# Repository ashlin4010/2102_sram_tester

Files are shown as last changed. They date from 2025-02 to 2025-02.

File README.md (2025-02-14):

# 2102 SRAM Tester #

A basic tester to quickly check 2102 RAM chips. This tester only performs rudimentary tests and is very lax with its timing so it may not fully detect marginal RAM chips.

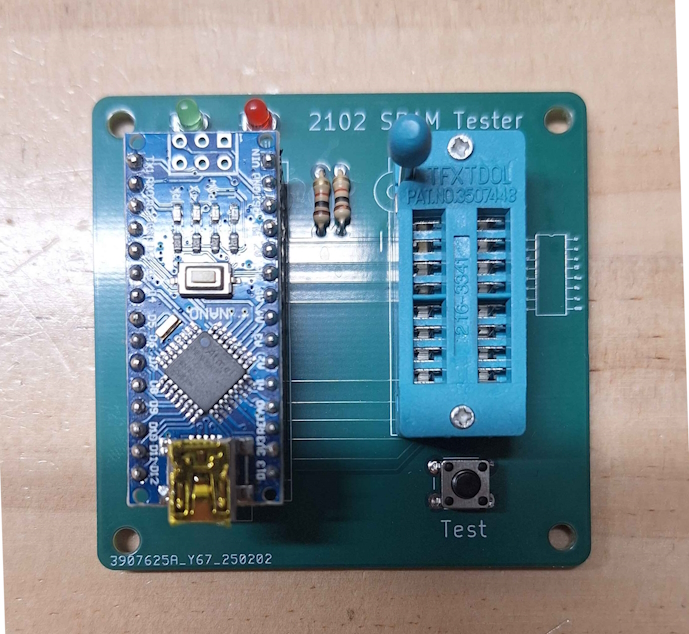
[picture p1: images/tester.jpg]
RAM tester PCB

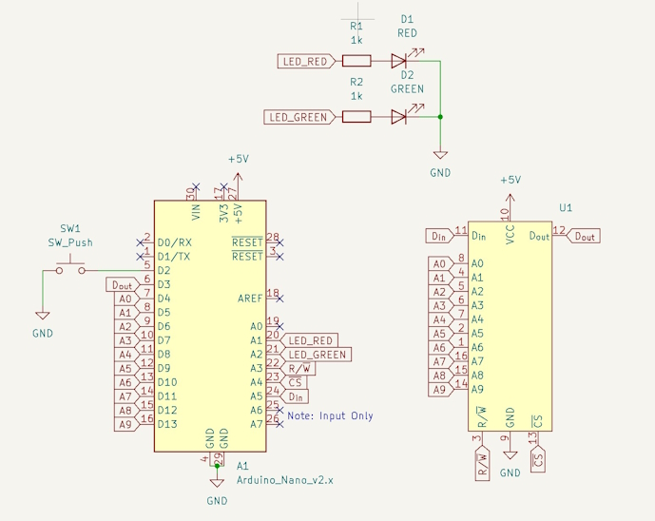
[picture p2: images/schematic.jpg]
RAM schematics


## Firmware ##
The firmware is a quick and dirty Arduino program and makes use of `digitalWrite` and is subsequently very slow. Things could be sped up significantly by writing the firmware in AVR and using timers and cycle counting. The circuit would also benefit from an external latch for the address lines.

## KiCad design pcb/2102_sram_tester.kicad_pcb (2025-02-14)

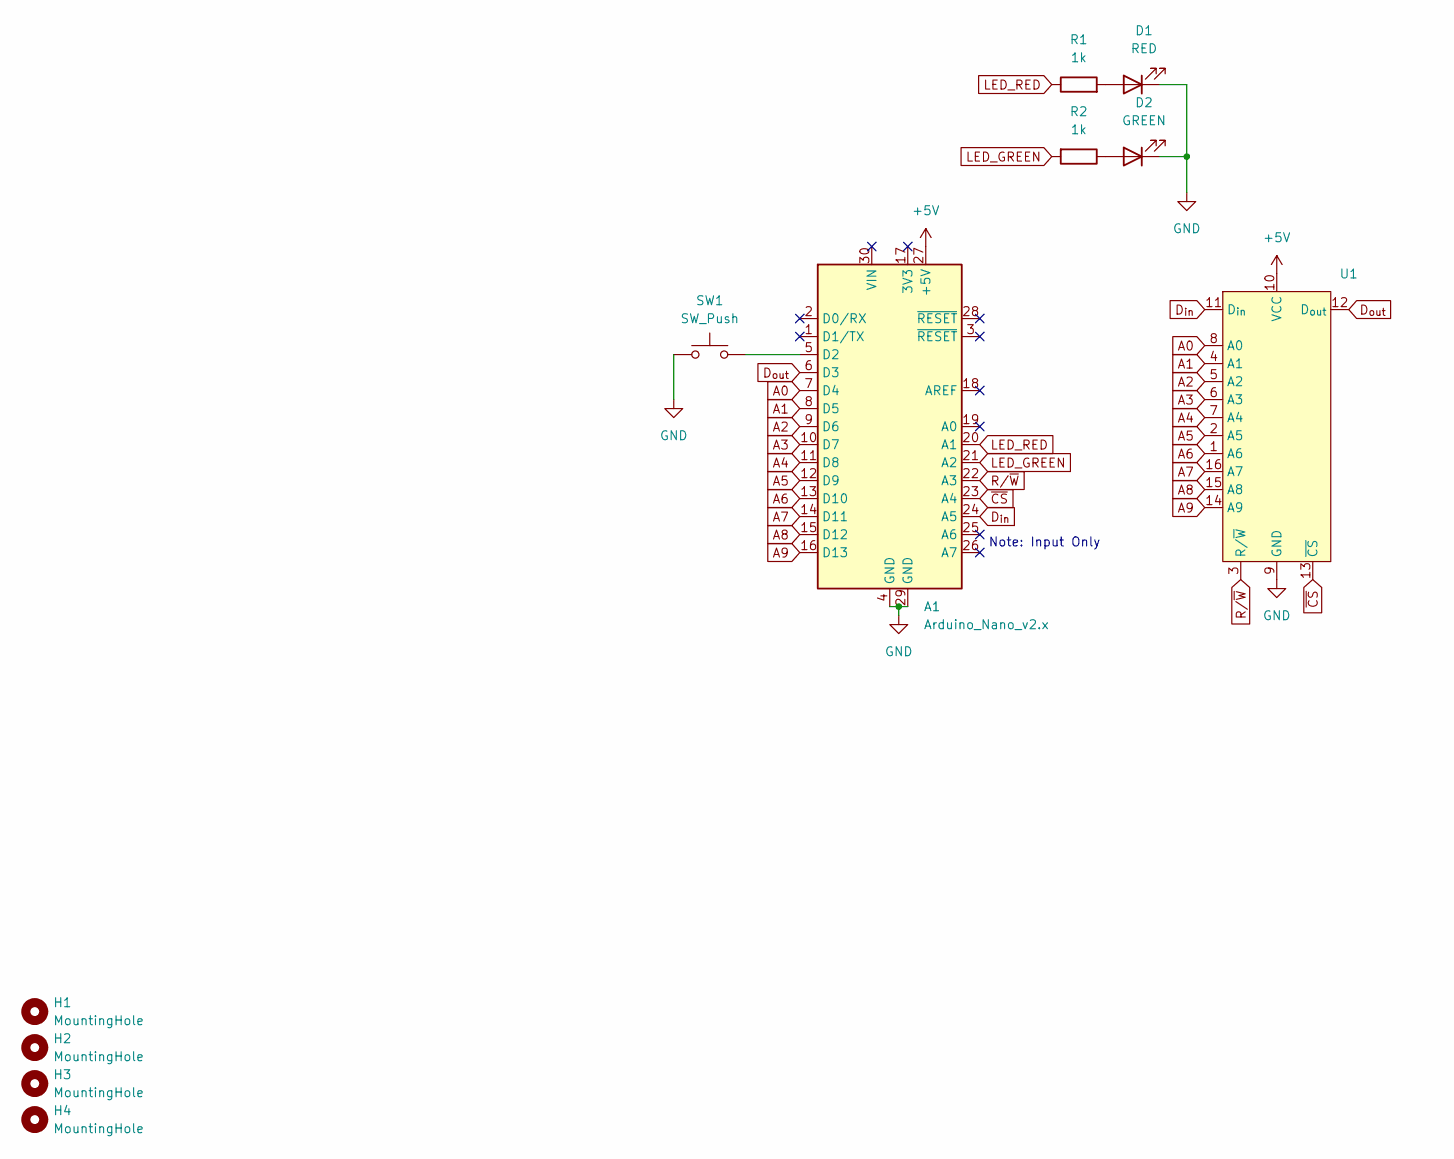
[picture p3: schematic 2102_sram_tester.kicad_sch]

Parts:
A1: Arduino_Nano_v2.x; Arduino_Nano
D1: RED; LED_D3.0mm
D2: GREEN; LED_D3.0mm
H1, H2, H3, H4: MountingHole; MountingHole_3.2mm_M3
R1, R2: 1k; R_Axial_DIN0204_L3.6mm_D1.6mm_P7.62mm_Horizontal
SW1: SW_Push; SW_PUSH_6mm
U1: DIP_Socket-16_W4.3_W5.08_W7.62_W10.16_W10.9_3M_216-3340-00-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

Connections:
+5V: A1.27 (+5V), U1.10 (VCC)
A0: A1.7 (D4), U1.8 (A0)
A1: A1.8 (D5), U1.4 (A1)
A2: A1.9 (D6), U1.5 (A2)
A3: A1.10 (D7), U1.6 (A3)
A4: A1.11 (D8), U1.7 (A4)
A5: A1.12 (D9), U1.2 (A5)
A6: A1.13 (D10), U1.1 (A6)
A7: A1.14 (D11), U1.16 (A7)
A8: A1.15 (D12), U1.15 (A8)
A9: A1.16 (D13), U1.14 (A9)
D_{in}: A1.24 (A5), U1.11 (D_{in})
D_{out}: A1.6 (D3), U1.12 (D_{out})
GND: A1.4 (GND), A1.29 (GND), D1.1 (K), D2.1 (K), SW1.1, U1.9 (GND)
LED_GREEN: A1.21 (A2), R2.2
LED_RED: A1.20 (A1), R1.1
unnamed: A1.5 (D2), SW1.2
unnamed: D1.2 (A), R1.2
unnamed: D2.2 (A), R2.1
R/~W: A1.22 (A3), U1.3 (R/~W)
~CS: A1.23 (A4), U1.13 (~CS)

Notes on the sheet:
Note: Input Only

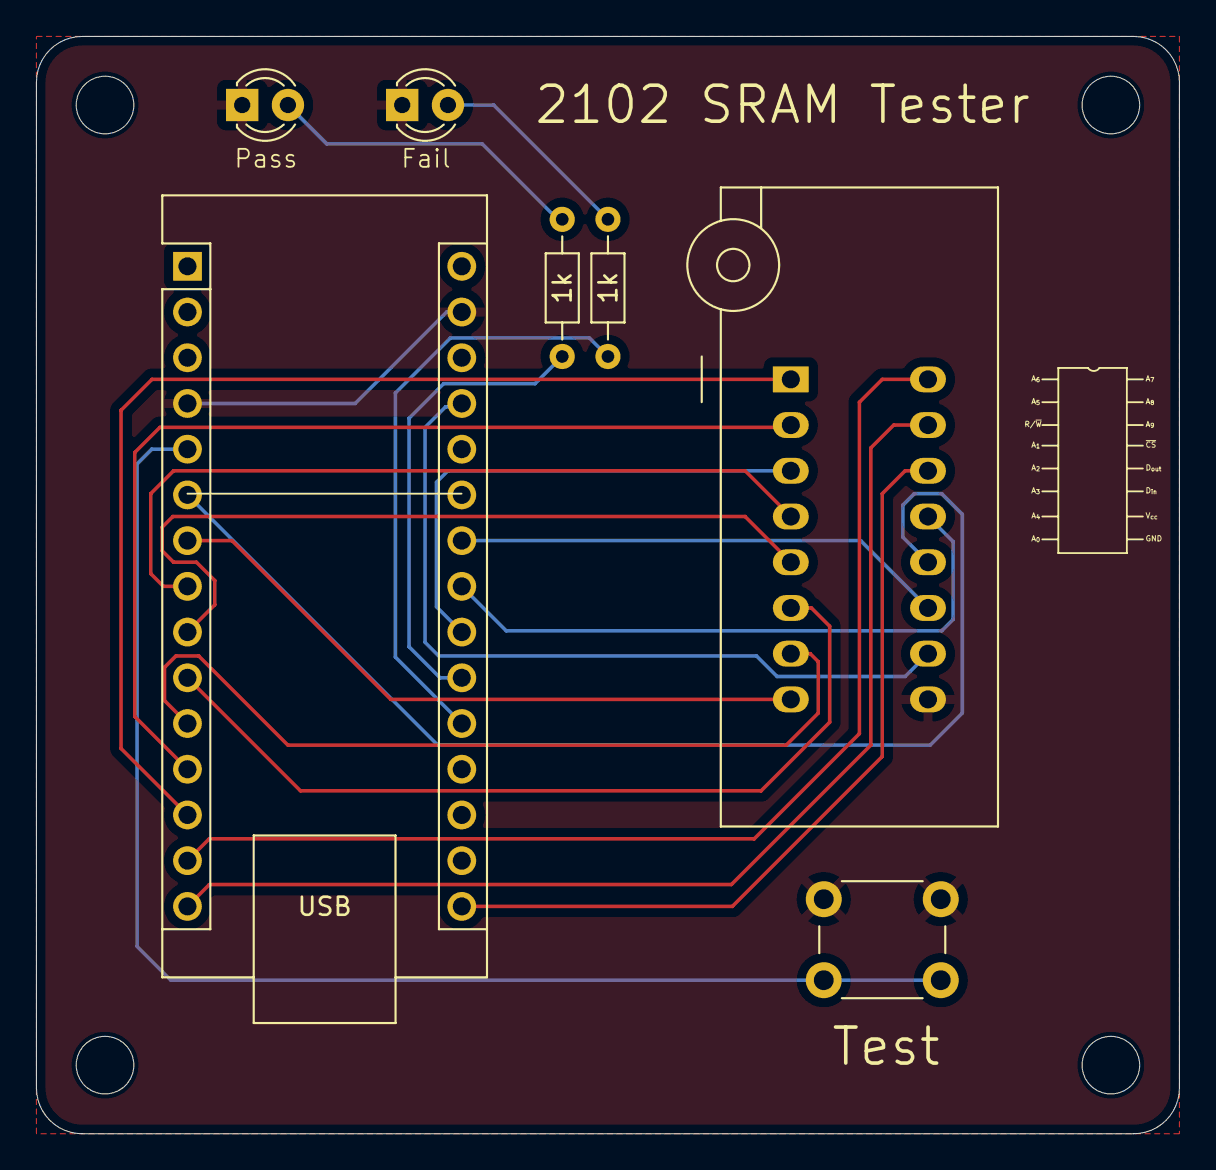
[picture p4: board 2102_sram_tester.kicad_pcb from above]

Board: 2 copper layers, 63.5 x 61.0 mm, 11 parts (0 on the bottom side), 21 nets.

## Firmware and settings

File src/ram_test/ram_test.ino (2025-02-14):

const uint8_t LED_RED = A1;
const uint8_t LED_GREEN = A2;
const uint8_t SRAM_A0 = 4;
const uint8_t SRAM_A1 = 5;
const uint8_t SRAM_A2 = 6;
const uint8_t SRAM_A3 = 7;
const uint8_t SRAM_A4 = 8;
const uint8_t SRAM_A5 = 9;
const uint8_t SRAM_A6 = 10;
const uint8_t SRAM_A7 = 11;
const uint8_t SRAM_A8 = 12;
const uint8_t SRAM_A9 = 13;
const uint8_t CS = A4;
const uint8_t DIN = A5;
const uint8_t DOUT = 3;
const uint8_t RW = A3;
const uint8_t BUTTON = 2; 
const uint8_t *ADDRESS[10] = {&SRAM_A0, &SRAM_A1, &SRAM_A2, &SRAM_A3, &SRAM_A4, &SRAM_A5, &SRAM_A6, &SRAM_A7, &SRAM_A8, &SRAM_A9 };
const uint8_t ADDRESS_COUNT = 10;
const uint16_t ADDRESS_MAX = 2 << ADDRESS_COUNT;

volatile bool is_running_tests = false;

void setup() {
  Serial.begin(9600);             // Debug 
  pinMode(BUTTON, INPUT_PULLUP);
  pinMode(LED_RED, OUTPUT);
  pinMode(LED_GREEN, OUTPUT);
  pinMode(CS, OUTPUT);
  pinMode(DIN, OUTPUT);
  pinMode(RW, OUTPUT);
  pinMode(DOUT, INPUT);

  digitalWrite(CS, HIGH);         // Chip select active low
  digitalWrite(RW, HIGH);         // Write active low

  // Set up SRAM address pins
  for (uint8_t i = 0; i < ADDRESS_COUNT; i++) {
    pinMode(*ADDRESS[i], OUTPUT);
  }
  attachInterrupt(digitalPinToInterrupt(BUTTON), buttonISR, RISING);
}

void buttonISR() {
  static unsigned long last_interrupt_time = 0;
  unsigned long interrupt_time = millis();

  if (interrupt_time - last_interrupt_time > 150) {
    is_running_tests = !is_running_tests;
  }
  last_interrupt_time = interrupt_time;
}

bool writeReadTest(uint16_t address, uint8_t value)  {
  // This code is very slow but is a basic test.
  // For better testing this code should be written with timers and in AVRC
  for(uint16_t b = 0; b < ADDRESS_COUNT; b++) {
    int bit = (address >> b) & 1;
    digitalWrite(*ADDRESS[b], bit);   
  }
  delayMicroseconds(1);             // Allow time to settle

  digitalWrite(DIN, value);    // Set bit to write
  digitalWrite(CS, 0);              // Write bit
  digitalWrite(RW, 0);
  digitalWrite(RW, 1);
  digitalWrite(CS, 1);
  delayMicroseconds(1);             // Wait
  digitalWrite(CS, 0);              // Read bit
  uint8_t value_out = digitalRead(DOUT);
  digitalWrite(CS, 1);
  return value_out == value;
}

void loop() {
  if(is_running_tests) {
    digitalWrite(LED_RED, LOW);
    for(uint16_t address = 0; (address < ADDRESS_MAX) && is_running_tests; address++) {

      bool testPass = writeReadTest(address, 1) && writeReadTest(address, 0) && writeReadTest(address, 1);

      if (!testPass) {
        digitalWrite(LED_RED, 1);
        is_running_tests = false;
        Serial.print("Test failed: ");
        Serial.println(address);
        break;
      }
    }
    // Flash green light at the end of the test
    if (is_running_tests){
      digitalWrite(LED_GREEN, HIGH);
      delay(100);
      digitalWrite(LED_GREEN, LOW);
      delay(100);
    }
  }
} 
